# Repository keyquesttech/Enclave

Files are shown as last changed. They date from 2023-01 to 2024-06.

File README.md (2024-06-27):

<p align="center" style="margin-bottom: 0px !important;">
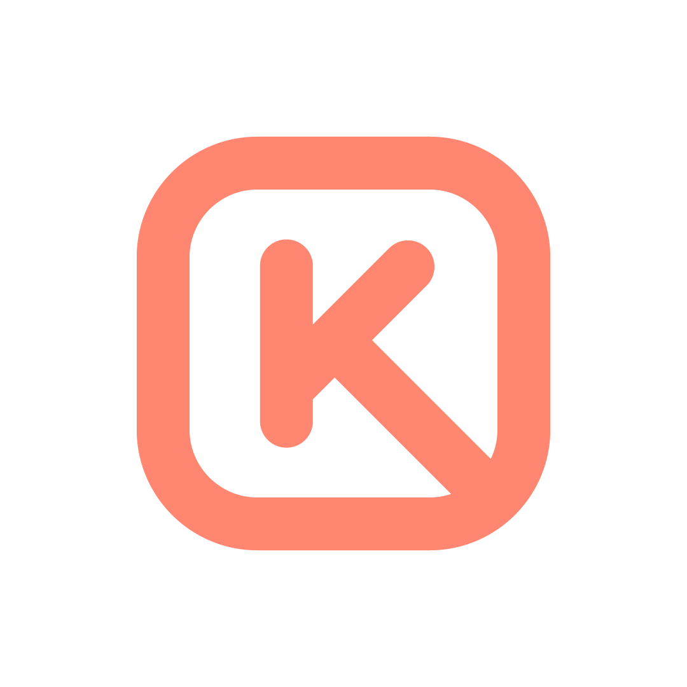
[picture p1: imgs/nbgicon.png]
Keyquest logo
  
</p>
<h1 align="center" style="margin-top: 0px;">Keyquest Keyboards</h1>
<p align="center" >Developed As Part Of My Industrial Design Thesis</p>
<p align="center" >Some Aspects Of This Project Are In Spanish</p>
<p align="center" >Developed by Matias M.</p>

<p align="center" style="margin-bottom: 0px !important;">
  <a href="https://github.com/Mathiaszmrga">
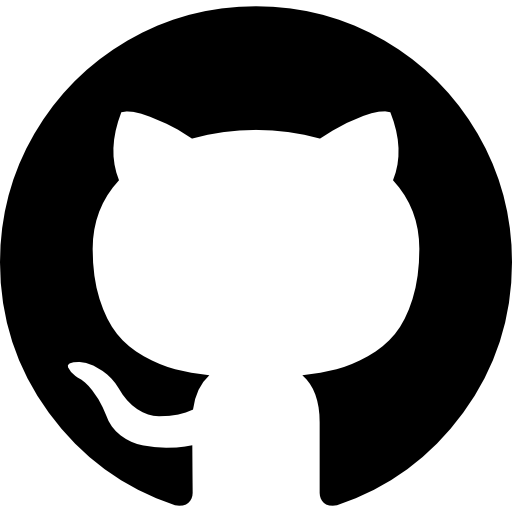
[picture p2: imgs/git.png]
    
  </a>
 <a href="https://www.behance.net/matiasms">
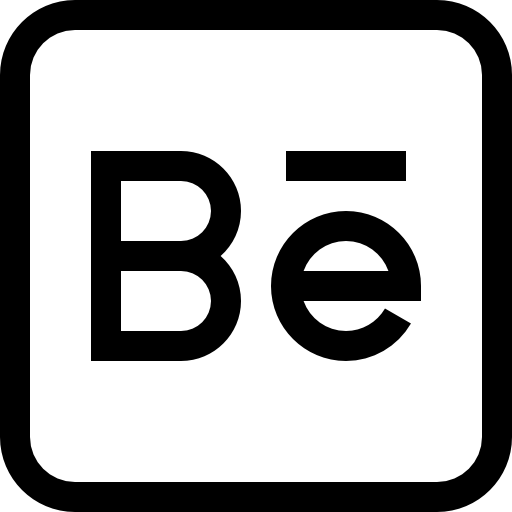
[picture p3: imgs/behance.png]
    
  </a>

<div align="center" >
  
  
  
  
  
  
</div>
  
<p align="center" style="margin-top: 100px !important;">
  <h2 align="center" style="margin-bottom: 0px;">Versions And Repo Content</h2>
</p>

<p align="center" style="margin-bottom: 0px !important;">
  <a href="https://github.com/keyquesttech/Enclave/tree/main/Enclave-1/stm">
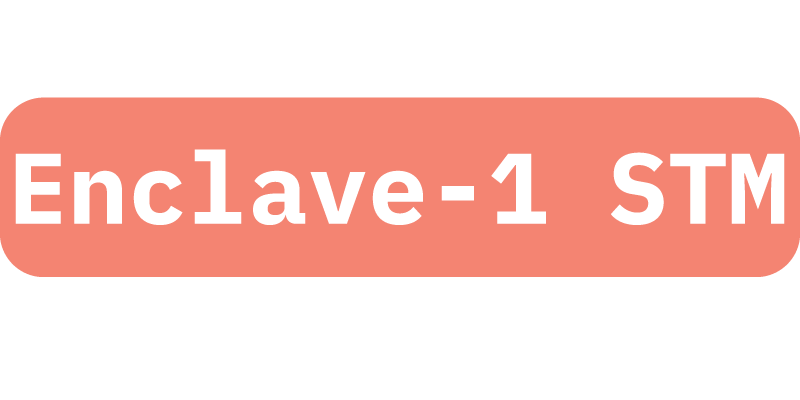
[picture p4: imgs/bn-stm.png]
    
  </a>
 <a href="https://github.com/keyquesttech/Enclave/tree/main/Enclave-1/avr">
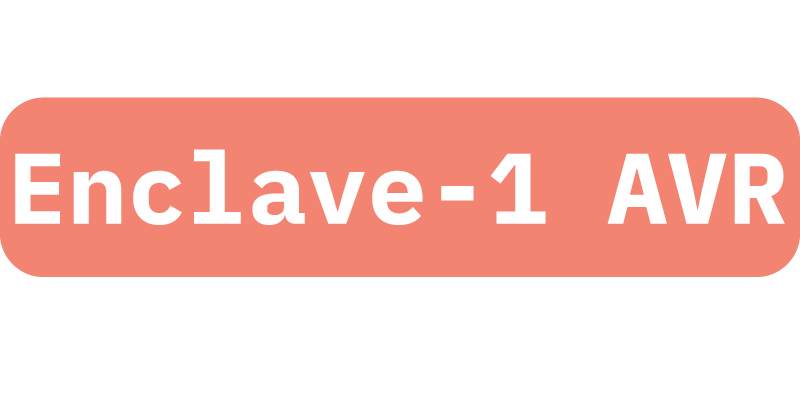
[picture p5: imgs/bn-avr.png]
    
  </a>
  
</p>

<p align="center" style="margin-top: 0px !important;">
  <h2 align="center" style="margin-bottom: 0px;">Table of Contents (Enclave-1)</h2>
</p>

<p align="center" style="margin-bottom: 0px !important;">
  adf
</p>

<p align="center" style="margin-bottom: 0px !important;">
  <h2 align="center" style="margin-top: 0px;"></h2>
</p>

- [Features](#Features)
- [Repo Content](#Repo-Content)
  - [STM](#STM)
  - [AVR](#AVR)
  - [Plate](#Plate)
- [Case](#Case)
- [Code](#Code)
  - [QMK](#QMK)
  - [VIA](#VIA)
  - [VIAL](#VIAL)
- [Suppliers](#Suppliers)
- [Contributing](#contributing)
- [Copyright and License](#copyright-and-license)

## Features:

- Lightweight.
- Cherry MX Compatible.
- Kailh Hotswap Sockets
- RGB Underglow.
- QMK, VIA And VIAL Compatible.
- Customizable.
- USB-C Interphase.
- Built In USB-HUB.

## Repo Content:

All files necessary for reproduction, manufacturing and modifications

| Branch | Content |
|--|--|
| AVR | Files for AVR (arduino) based PCB |
| STM| Files for STM based PCB |
| Plate| Files for FR-4 plate manufacturing |
| Imgs| Images on this repo and product pics |

### STM:

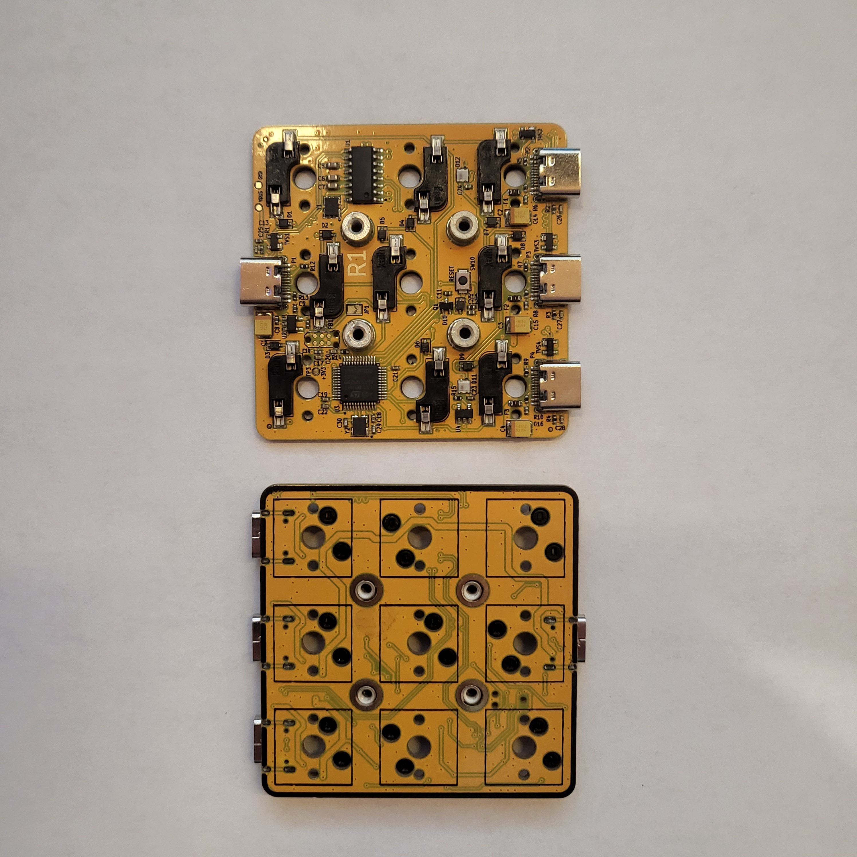
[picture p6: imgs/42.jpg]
  

| Branch | Content |
|--|--|
| 3D| PCB 3D files |
| Datasheet| Datasheet of components used |
| Docs| DXF of PCB outline |
| ZIP Full| KiCad full source file |
| Enclave_stm_sch.pdf| PDF schematic |
| Enclave_stm_BOM.pdf| PDF Bill of materials|

This version of the PCB didn't work at first and it was forgotten in favor of AVR. Use at your own risk.

### AVR:

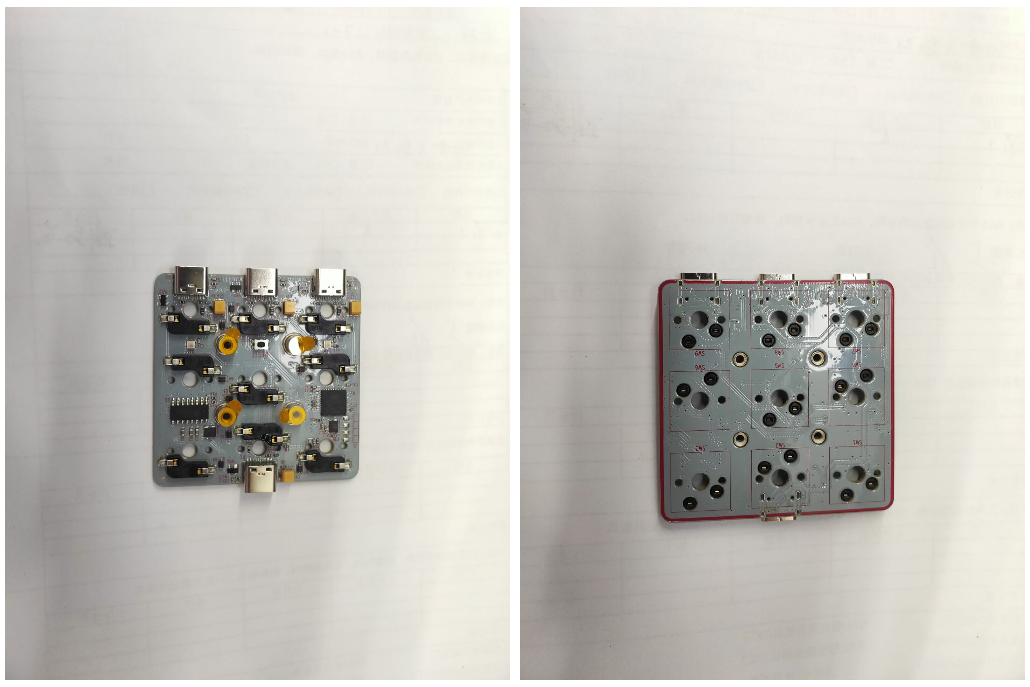
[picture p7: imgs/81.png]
  

| Branch | Content |
|--|--|
| Datasheet| Datasheet of components used |
| Docs| DXF of PCB outline |
| Production| Production files |
| ZIP Full| KiCad full source file |
| Enclave_avr_BOM.pdf| PDF Bill of materials|
| Enclave_avr_sch.pdf| PDF schematic |

### Plate:

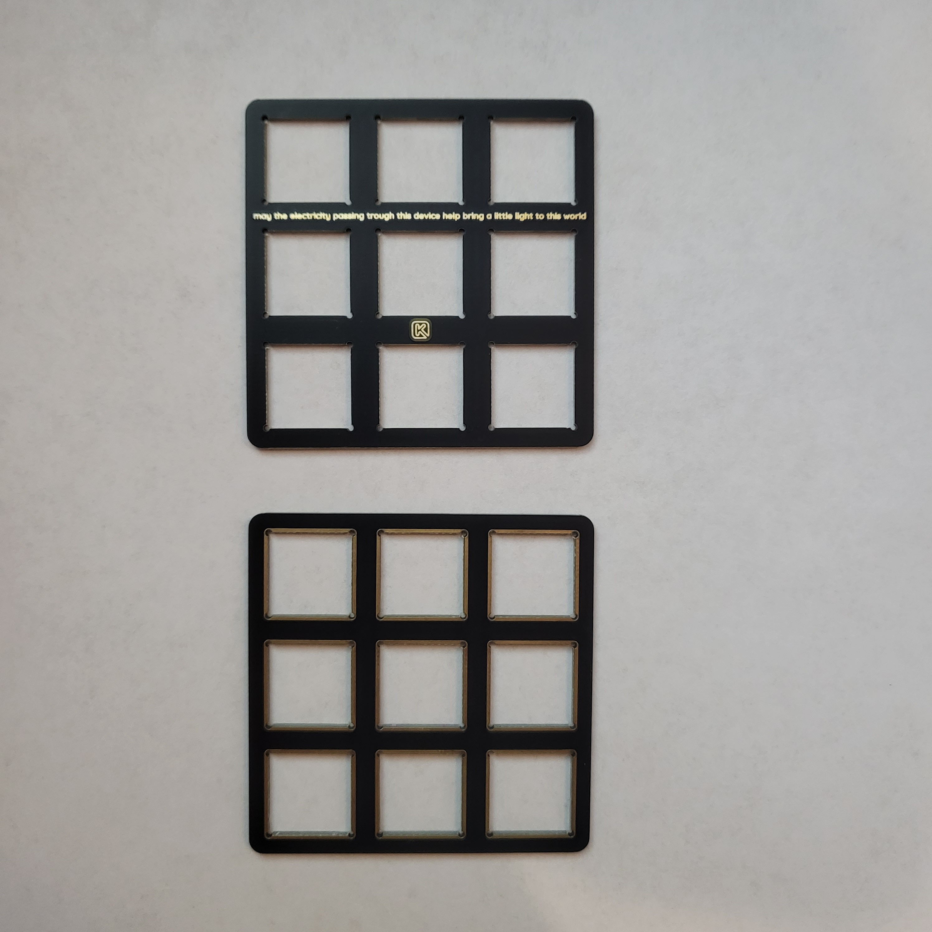
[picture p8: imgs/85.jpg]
  

| Branch | Content |
|--|--|
| DXF SRC| FR-4 Plate DXF source file |
| EasyEDA SRC| EasyEDA JSON PCB source file |
| Plate Gerber| Production files |

## Case:

  

| Branch | Content |
|--|--|
| Case_one_part.step| STEP file of for the case |
| Case_one_part_Drawing.pdf| Technical drawings of the case |

## Code:

Source code files.
- [QMK repo](https://github.com/qmk/qmk_firmware)
- [VIA repo](https://github.com/the-via/keyboards)
- [VIAL repo](https://github.com/vial-kb/vial-qmk)

### QMK:

QMK code, just add to the kyeboards directory and compile or edit as desired. it's currently merged into main so it works on official website and tools.

### VIA:

VIA can be used for local upload of JSON but it's currently merged into main so it works on official website.

### VIAL:

VIAL Source code, merged into main so it works when compiling official branch.

## Suppliers:

**Information on the service providers used for the project**

| Supplier| Contact| Thing |
|--|--|-|
| Elecrow| [Elecrow](https://www.elecrow.com/) | CNC machining
| Elecrow| [Elecrow](https://www.elecrow.com/) | PCB manufacturing
| Upwork| [Alberto M.](https://www.upwork.com/freelancers/~01b4ecb4cf82c98eb9) | PCB design
| Alibaba| echo@hzyinzheng.com | Adhesive feet

## Contributing

All contributions are welcome and encouraged.

## Copyright and License

Released under the MIT license.

<hr>

<div align="center">
  <strong><h1>Other projects from the autor (me)</h1></strong>
</div>

3D models / Prints:
 - [Mason jar ashtray](https://www.printables.com/model/918749-ashtray-mason-jar)
A mason jar attachment to make almost every jar in to an ashtray.

Printer mods:
 - [Servo nozzle brush (printables).](https://www.printables.com/model/913748-ratrig-vcore-331-servo-nozzle-brush)
A servo attached nozzle brush.
 - [Servo nozzle brush (github).](https://github.com/keyquesttech/Ratrig-Vcore-3-3.1-servo-nozzle-brush)
A servo attached nozzle brush.
 - [Endstops.](https://github.com/keyquesttech/3d_printer_endstops)
A collection of custom endstops for 3d printers or cnc machines. 
 - [Thermexp.](https://github.com/keyquesttech/Thermexp)
A PCB to add more thermistors to a klipper printer.

Chrome extensions:
 - [Youtube ads auto skip.](https://github.com/keyquesttech/chrome-extensions)
A chrome extension that emulates a click and auto skips youtube ads. Works even after adblock prevention measures.

Keyboards:
 - [Enclave.](https://github.com/keyquesttech/Enclave)
A custom mechanical switch macro pad. Works on QMK and can be used with klipper.

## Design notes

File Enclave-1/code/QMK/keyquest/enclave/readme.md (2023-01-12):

# Enclave-1

ok

Enclave 1 is a fully programmable 9-key macropad + usb hub ideal for those constantly on the move that need to adapt to any situation. Besides being a full-fledged macropad, it can also be used as the main hub for all your other devices such as keyboards, dongles, drives, etc.

* Keyboard Maintainer: [KeyQuest](https://github.com/KeyQuest)

Compile example for this keyboard (after setting up your build environment):

    make keyquest/enclave:default

Enter the bootloader in 3 ways:

* **Bootmagic reset**: Hold down the  top left key and plug in the keyboard.
* **Physical reset button**: Briefly press the button on the back of the PCB.

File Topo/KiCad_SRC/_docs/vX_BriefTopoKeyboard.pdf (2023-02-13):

### Brief diseño de teclado Topo

Funciones:
- Switches low profile “KAILH-PG1350-1U-NOLED”
- https://github.com/keebio/Keebio-Parts.pretty
- Estabilizador para teclas de 2U “KAILH PG1350 CHOC 2U STABILIZER PCB CUTOUT”
- https://github.com/keebio/Keebio-Parts.pretty
- 4x LEDs:
- Rojo para poder.
- 3 blancos conectados a pines.
- 1x USB-C.
- Standoffs SMD.

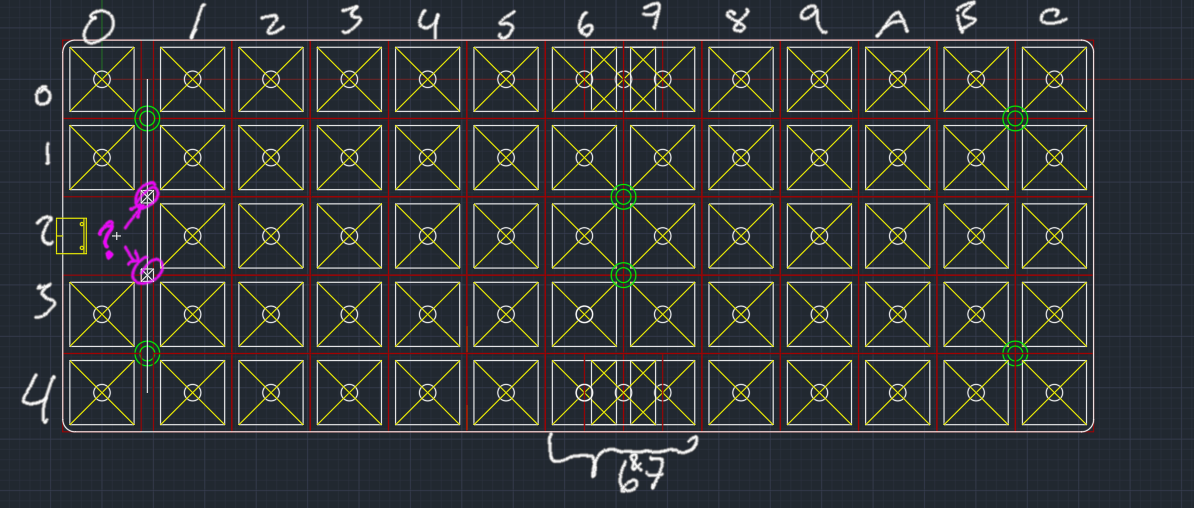
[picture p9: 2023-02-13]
Topo/KiCad_SRC/_docs/v1_layout_mod.png

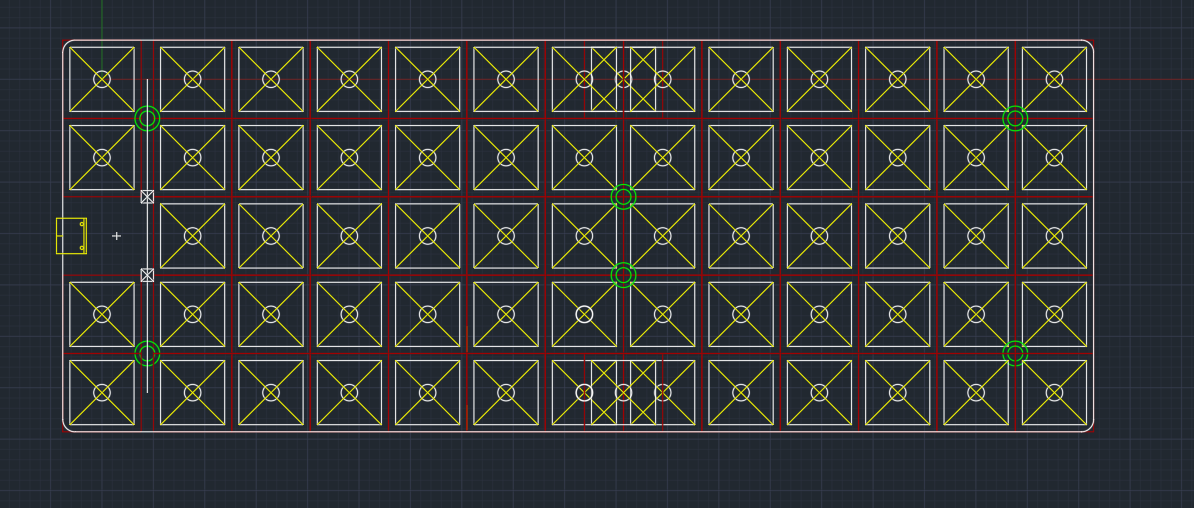
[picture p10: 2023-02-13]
Topo/KiCad_SRC/_docs/v1_layout.png

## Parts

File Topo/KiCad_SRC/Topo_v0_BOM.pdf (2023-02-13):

Topo_v0

Source: | Topo_v0.kicad_sch
Date: | Sun 12 Feb 2023 08:32:24 PM -04
Tool: | Eeschema 6.0.11-2627ca5db0~126~ubuntu22.04.1
Component Count: | 296
Item | Qty | Ref(s) | Value | Digi-Key | LCSC | Manufacturer | Mouser | Package_LCSC | Part Number
1 | 1 | C1 | 100uF/6.3V | 478-3877-1-ND | C7195 | KYOCERA AVX | 581-TAJB107M006R | CASE-B-3528 | TAJB107M006RNJ
2 | 6 | C2-7 | 1uF/16V | 1276-1067-1-ND | C29266 | Samsung Electro-Mechanics | 187-CL05A105KO5NNNC | 0402 | CL05A105KO5NNNC
3 | 72 | C8-79 | 0.1uF/16V | 1276-1001-1-ND | C1525 | Samsung Electro-Mechanics | 187-CL05B104KO5NNNC | 0402 | CL05B104KO5NNNC
4 | 1 | C80 | 1nF/50V | 1276-1032-1-ND | C14442 | Samsung Electro-Mechanics | 187-CL05B102KB5NNNC | 0402 | CL05B102KB5NNNC
5 | 2 | C81-82 | 22pF/50V | 1276-1116-1-ND | C70464 | Samsung Electro-Mechanics | 187-CL05C220JB5NNNC | 0402 | CL05C220JB5NNNC
6 | 64 | D1-64 | SD103AWS-TP | SD103AWSTPMSCT-ND | C779513 | Micro Commercial Co | 833-SD103AWS-TP | SOD-323 | SD103AWS-TP
7 | 66 | D65-130 | SK6812MINI-E | 1528-4960-ND | C5149201 | Adafruit Industries LLC | 485-4960 | SMD | 4960
8 | 1 | FB1 | BLM15PX221SN1D | 490-11021-1-ND | C160973 | Murata Electronics | 81-BLM15PX221SN1D | 0402 | BLM15PX221SN1D
9 | 6 | H1-6 | MountingHole_Pad | 732-7089-1-ND | - - - | Würth Elektronik | 710-9774040151R | - - - | 9774040151R
10 | 1 | J1 | AVR-ISP | 609-4381-ND | - - - | Amphenol ICC (FCI) | 649-10112684G0304ULF | - - - | 10112684-G03-04ULF
11 | 1 | P1 | Port1 | - - - | C165948 | Korean Hroparts Elec | - - - | SMD | TYPE-C-31-M-12
12 | 1 | R1 | 1M0 | 311-1.00MLRCT-ND | C138033 | YAGEO | 603-RC0402FR-071ML | 0402 | RC0402FR-071ML
13 | 2 | R2-3 | 10K0 | 311-10.0KLRCT-ND | C60490 | YAGEO | 603-RC0402FR-0710KL | 0402 | RC0402FR-0710KL
14 | 2 | R4, R5 | 5K1 | 311-5.10KLRCT-ND | C105872 | YAGEO | 603-RC0402FR-075K1L | 0402 | RC0402FR-075K1L
15 | 1 | R6 | 499R | 311-499LRCT-ND | C137970 | YAGEO | 603-RC0402FR-07499RL | 0402 | RC0402FR-07499RL
16 | 2 | R7-8 | 22R0 | 311-22.0LRCT-ND | C114765 | YAGEO | 603-RC0402FR-0722RL | 0402 | RC0402FR-0722RL
17 | 1 | SW1 | RESET | CKN10587CT-ND | C221904 | C&K | 611-PTS830GM140GSMTR | SMD | PTS830GM140 SMTR LFS
18 | 1 | SW2 | SW_DIP_x01 | 2223-DS04-254-1-01BK-SMT-ND | C600988 | CUI Devices | 490-DS04254101BK-SMT | SMD,3.5x6.2mm | DS04-254-1-01BK-SMT
19 | 62 | SW3-64 | Choc V1 | - - - | - - - | Cherry AG | - - - | - - - | Cherry MX
21 | 1 | TVS1 | PRTR5V0U2X | 1727-3884-1-ND | C12333 | Nexperia USA Inc. | 771-PRTR5V0U2X-T/R | SOT-143 | PRTR5V0U2X,215
22 | 1 | U1 | ATmega32U4-M | ATMEGA32U4-MURCT-ND | C45874 | Microchip Technology | 556-ATMEGA32U4-MUR | VQFN-44-EP(7x7) | ATMEGA32U4-MUR
23 | 1 | Y1 | 16MHz | 535-10267-1-ND | C1985423 | Abracon LLC | 815-ABM8G-16-18D2Y | SMD-4P | ABM8G-16.000MHZ-18-D2Y-T

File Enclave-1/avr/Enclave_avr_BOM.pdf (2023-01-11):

# ENCLAVE_v0

Source: ENCLAVE_v0.kicad_sch

Date: Thu 16 Jun 2022 02:48:39 PM -04

Tool: Eeschema 6.0.5-a6ca702e91~116~ubuntu22.04.1

Component Count: 97

Item | Qty | Reference(s) | Value | Manufacturer | Part Number | Digi-Key | LCSC | Mouser
1 | 4 | C1-4 | 100uF/6.3V | KYOCERA AVX | TAJB107M006RNJ | 478-3877-1-ND | C7195 | 581-TAJB107M006R
2 | 3 | C5-7 | 10uF/10V | Samsung Electro-Mechanics | CL10A106MP8NNNC | 1276-1871-1-ND | C85713 | 187-CL10A106MP8NNNC
3 | 9 | C8-16 | 1uF/16V | Samsung Electro-Mechanics | CL05A105KO5NNNC | 1276-1067-1-ND | C29266 | 187-CL05A105KO5NNNC
4 | 8 | C17-24 | 0.1uF/16V | Samsung Electro-Mechanics | CL05B104KO5NNNC | 1276-1001-1-ND | C1525 | 187-CL05B104KO5NNNC
5 | 4 | C25-28 | 1nF/50V | Samsung Electro-Mechanics | CL05B102KB5NNNC | 1276-1032-1-ND | C14442 | 187-CL05B102KB5NNNC
6 | 2 | C29-30 | 22pF/50V | Samsung Electro-Mechanics | CL05C220JB5NNNC | 1276-1116-1-ND | C70464 | 187-CL05C220JB5NNNC
7 | 9 | D1-9 | SD103AWS-TP | Micro Commercial Co | SD103AWS-TP | SD103AWSTPMSCT-ND | C779513 | 833-SD103AWS-TP
8 | 2 | D10-11 | WS2812B-2020 | Worldsemi | WS2812B-Mini | 1528-4684-ND | C2976072 | 485-4684
9 | 3 | F1-3 | 350mA | YAGEO | SMD0603B035TF | 13-SMD0603B035TFCT-ND | C269154 | 603-SMD0603B035TF
10 | 1 | FB1 | BLM15PX221SN1D | Murata Electronics | BLM15PX221SN1D | 490-11021-1-ND | C160973 | 81-BLM15PX221SN1D
11 | 4 | H1-4 | MountingHole_Pad | Würth Elektronik | 9774040151R | 732-7089-1-ND | - - - | 710-9774040151R
12 | 1 | J1 | AVR-ISP | Amphenol ICC (FCI) | 10112684-G03-04ULF | 609-4381-ND | - - - | 649-10112684G0304ULF
13 | 4 | P1-4 | Port1-4 | Korean Hroparts Elec | TYPE-C-31-M-12 | - - - | C165948 | - - -
17 | 4 | R1-4 | 1M0 | YAGEO | RC0402FR-071ML | 311-1.00MLRCT-ND | C138033 | 603-RC0402FR-071ML
18 | 6 | R5-10 | 56K0 | YAGEO | RC0402FR-0756KL | 311-56.0KLRCT-ND | C114756 | 603-RC0402FR-0756KL
19 | 1 | R11 | 10K0 | YAGEO | RC0402FR-0710KL | 311-10.0KLRCT-ND | C60490 | 603-RC0402FR-0710KL
20 | 2 | R12-13 | 5K1 | YAGEO | RC0402FR-075K1L | 311-5.10KLRCT-ND | C105872 | 603-RC0402FR-075K1L
21 | 1 | R14 | 499R | YAGEO | RC0402FR-07499RL | 311-499LRCT-ND | C137970 | 603-RC0402FR-07499RL
22 | 2 | R15-16 | 22R0 | YAGEO | RC0402FR-0722RL | 311-22.0LRCT-ND | C114765 | 603-RC0402FR-0722RL
23 | 9 | SW1-9 | Cherry MX | Cherry AG | Cherry MX | - - - | - - - | - - -
24 | 1 | SW10 | RESET | C&K | KMR241GLFS | 401-1431-1-ND | C221682 | 611-KMR241GLFS
25 | 9 | SWS1-9 | Hot Swapping PCB Socket | Kaihua Electronics | CPG151101S11 | - - - | C2803348 | - - -
26 | 4 | TVS1-4 | PRTR5V0U2X | Nexperia USA Inc. | PRTR5V0U2X,215 | 1727-3884-1-ND | C12333 | 771-PRTR5V0U2X-T/R
27 | 1 | U1 | SL2.1A | CoreChips | SL2.1A | - - - | C192893 | - - -
28 | 1 | U2 | ATmega32U4-M | Microchip Technology | ATMEGA32U4-MUR | ATMEGA32U4-MURCT-ND | C45874 | 556-ATMEGA32U4-MUR
29 | 1 | Y1 | 12MHz | Abracon LLC | ABM8G-12.000MHZ-4Y-T3 | 535-10901-1-ND | C50430 | 815-ABM8G-12-4YT3
30 | 1 | Y2 | 16MHz | Abracon LLC | ABM8G-16.000MHZ-18-D2Y-T | 535-10267-1-ND | C1985423 | 815-ABM8G-16-18D2Y

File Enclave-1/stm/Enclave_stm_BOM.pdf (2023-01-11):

ONO_v0

Source: ONO_v0.kicad_sch

Date: Wed 25 May 2022 01:04:23 PM -04

Tool: Eeschema 6.0.5-a6ca702e91~116~ubuntu22.04.1

Component Count: 99

Item | Qty | Reference(s) | Value | Manufacturer | Part Number | Digi-Key | LCSC | Mouser
1 | 4 C1-4 | | 100uF/6.3V | KYOCERA AVX | TAJB107M006RNJ | 478-3877-1-ND | C7195 | 581-TAJB107M006R
2 | 3 C5-7 | | 10uF/10V | Samsung Electro-Mechanics | CL10A106MP8NNNC | 1276-1871-1-ND | C85713 | 187-CL10A106MP8NNNC
3 | 9 C8-16 | | 1uF/16V | Samsung Electro-Mechanics | CL05A105KO5NNNC | 1276-1067-1-ND | C29266 | 187-CL05A105KO5NNNC
4 | 8 C17-24 | | 0.1uF/16V | Samsung Electro-Mechanics | CL05B104KO5NNNC | 1276-1001-1-ND | C1525 | 187-CL05B104KO5NNNC
5 | 4 C25-28 | | 1nF/50V | Samsung Electro-Mechanics | CL05B102KB5NNNC | 1276-1032-1-ND | C14442 | 187-CL05B102KB5NNNC
6 | 2 C29-30 | | 10pF/50V | Samsung Electro-Mechanics | CL05C100JB5NNNC | 1276-1139-1-ND | C32949 | 187-CL05C100JB5NNNC
7 | 10 D1-10 | | SD103AWS-TP | Micro Commercial Co | SD103AWS-TP | SD103AWSTPMSCT-ND | C779513 | 833-SD103AWS-TP
8 | 2 D11-12 | | WS2812B-2020 | Worldsemi | WS2812B-Mini | 1528-4684-ND | C2976072 | 485-4684
9 | 3 F1-3 | | 350mA | YAGEO | SMD0603B035TF | 13-SMD0603B035TFCT-ND | C269154 | 603-SMD0603B035TF
10 | 1 FB1 | | BLM15PX221SN1D | Murata Electronics | BLM15PX221SN1D | 490-11021-1-ND | C160973 | 81-BLM15PX221SN1D
11 | 4 H1-4 | | MountingHole_Pad | Würth Elektronik | 9774040151R | 732-7089-1-ND | - - - | 710-9774040151R
12 | 4 P1-4 | | Port1-4 | Korean Hroparts Elec | TYPE-C-31-M-12 | - - - | C165948 | - - -
13 | 1 Q1 | | PDTC143ZU,115 | Nexperia USA Inc. | PDTC143ZU,115 | 1727-1714-1-ND | C282553 | 771-PDTC143ZU115
14 | 4 R1-4 | | 1M0 | YAGEO | RC0402FR-071ML | 311-1.00MLRCT-ND | C138033 | 603-RC0402FR-071ML
15 | 6 R5-10 | | 56K0 | YAGEO | RC0402FR-0756KL | 311-56.0KLRCT-ND | C114756 | 603-RC0402FR-0756KL
16 | 1 R11 | | 10K0 | YAGEO | RC0402FR-0710KL | 311-10.0KLRCT-ND | C60490 | 603-RC0402FR-0710KL
17 | 2 R12-13 | | 5K1 | YAGEO | RC0402FR-075K1L | 311-5.10KLRCT-ND | C105872 | 603-RC0402FR-075K1L
18 | 1 R14 | | 1K5 | YAGEO | RC0402FR-071K5L | 311-1.50KLRCT-ND | C114759 | 603-RC0402FR-071K5L
19 | 1 R15 | | 499R | YAGEO | RC0402FR-07499RL | 311-499LRCT-ND | C137970 | 603-RC0402FR-07499RL
20 | 9 SW1-9 | | Cherry MX | Cherry AG | Cherry MX | - - - | - - - | - - -
21 | 1 SW10 | | RESET | Omron Electronics Inc-EMC Div | B3U-1000P | SW1020CT-ND | C231329 | 653-B3U-1000P
22 | 9 SWS1-9 | | Hot Swapping PCB Socket | Kaihua Electronics | CPG151101S11 | - - - | C2803348 | - - -
23 | 4 TVS1-4 | | PRTR5V0U2X | Nexperia USA Inc. | PRTR5V0U2X,215 | 1727-3884-1-ND | C12333 | 771-PRTR5V0U2X-T/R
24 | 1 U1 | | SL2.1A | CoreChips | SL2.1A | - - - | C192893 | - - -
25 | 1 U2 | | TLV73333PDBV | Texas Instruments | TLV73333PDBVR | 296-40673-1-ND | C134139 | 595-TLV73333PDBVR
26 | 1 U3 | | STM32F303CBTx | STMicroelectronics | STM32F303CBT6 | 497-17421-ND | C108516 | 511-STM32F303CBT6
27 | 1 U4 | | 74LVC1G34 | Texas Instruments | SN74LVC1G34DBVR | 296-17893-1-ND | C840096 | 595-SN74LVC1G34DBVR
28 | 2 Y1-2 | | 12MHz | Abracon LLC | ABM8G-12.000MHZ-4Y-T3 | 535-10901-1-ND | C50430 | 815-ABM8G-12-4YT3

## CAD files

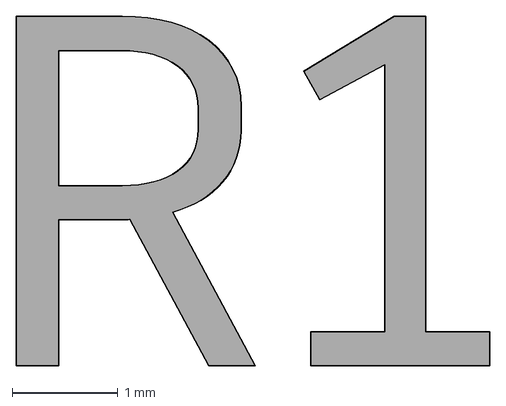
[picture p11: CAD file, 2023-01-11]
Enclave-1/avr/Docs/Rev_logo.dxf
4.48 x 3.31 mm

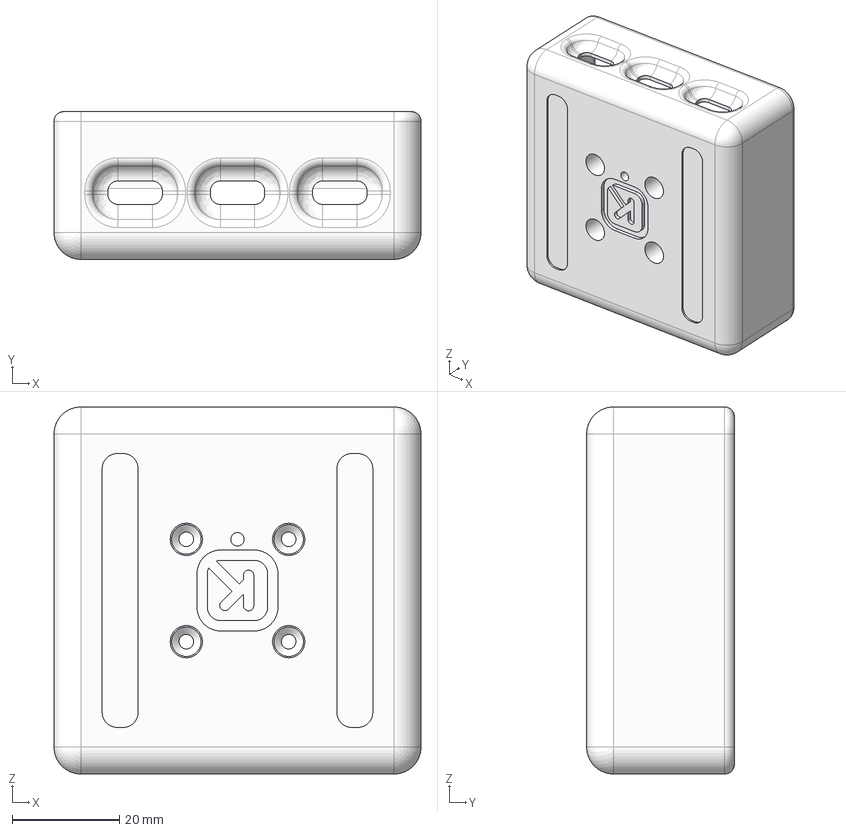
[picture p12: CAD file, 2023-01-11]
Enclave-1/case/Case_one_part.step
68.3 x 27.5 x 68.3 mm

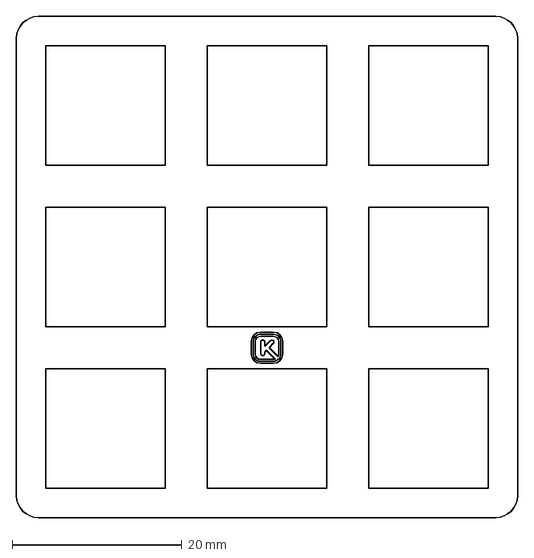
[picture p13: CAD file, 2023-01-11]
Enclave-1/plate/DXF_src/FR-4_plate_V1.dxf
59.1 x 59.1 mm

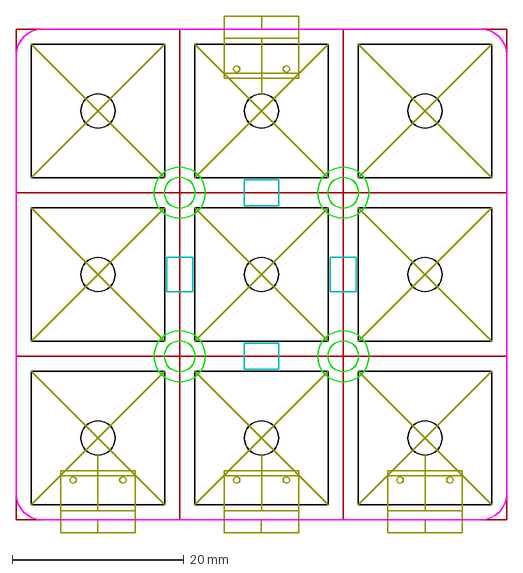
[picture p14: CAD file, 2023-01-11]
Enclave-1/stm/Docs/Outline.dxf
57.2 x 60.2 mm

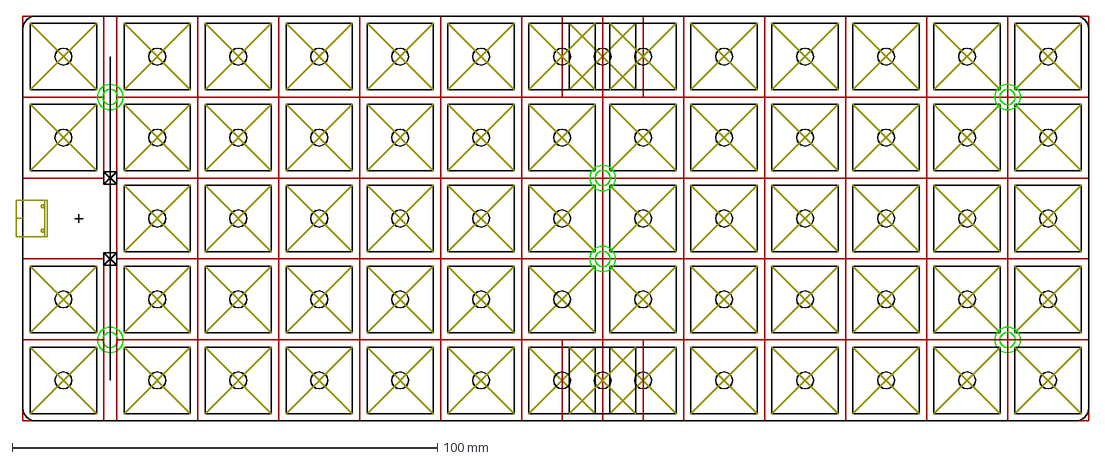
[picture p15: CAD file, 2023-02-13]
Topo/KiCad_SRC/_docs/v1_Outline.dxf
252.2 x 95.3 mm

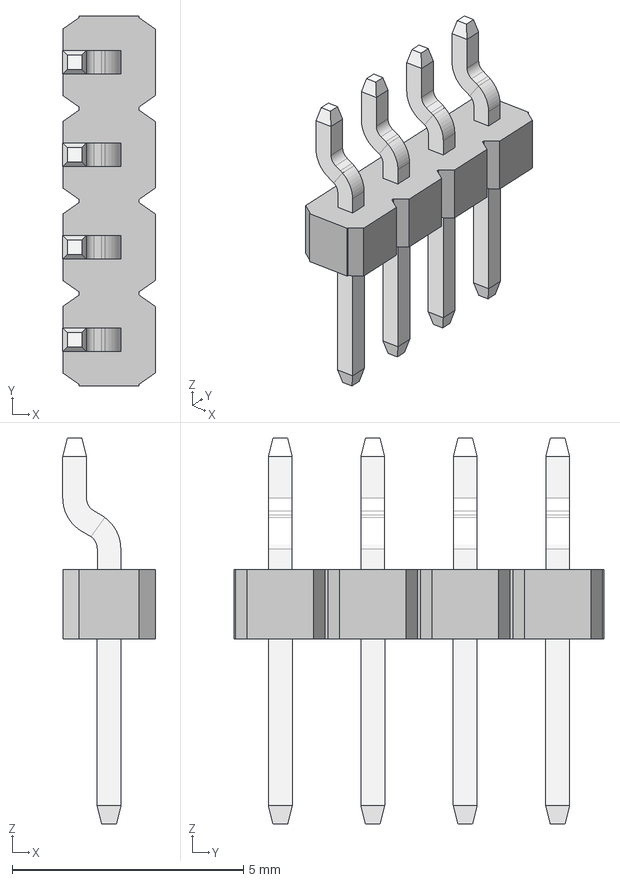
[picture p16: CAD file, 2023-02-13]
Topo/KiCad_SRC/_local/PinHeader_1x04_Amphenol_10112684-G03-04ULF.step
2.00 x 8.00 x 8.35 mm

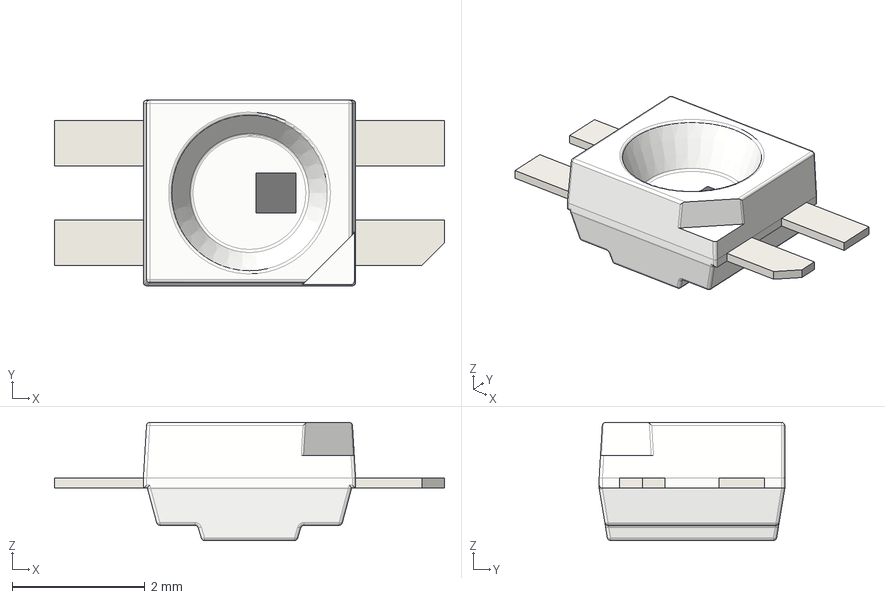
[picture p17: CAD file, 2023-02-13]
Topo/KiCad_SRC/_local/LED_OPSCO-Optoelectronics_SK6812MINI-E.step
5.88 x 2.80 x 1.78 mm

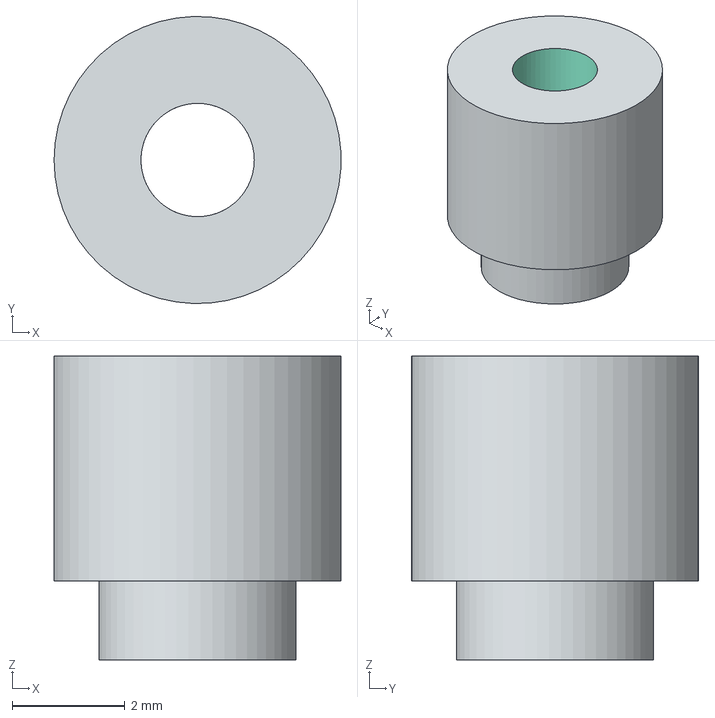
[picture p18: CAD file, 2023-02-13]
Topo/KiCad_SRC/_local/Standoff_M2d5_Wurth_9774040151R.step
5.10 x 5.10 x 5.40 mm

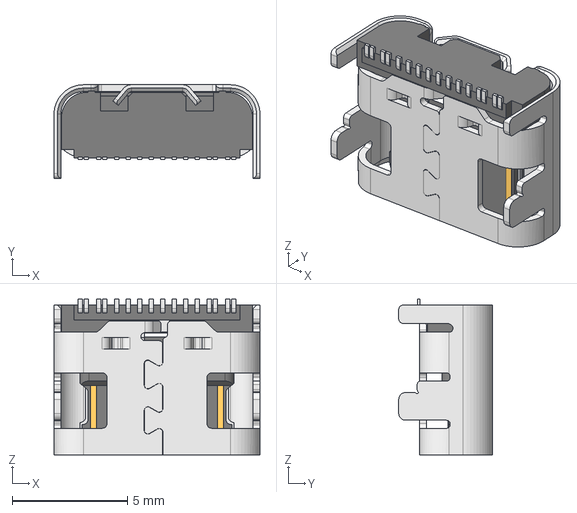
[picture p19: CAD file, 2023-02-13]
Topo/KiCad_SRC/_local/USB_C_Receptacle_Molex_2171790001.step
8.94 x 4.06 x 6.75 mm

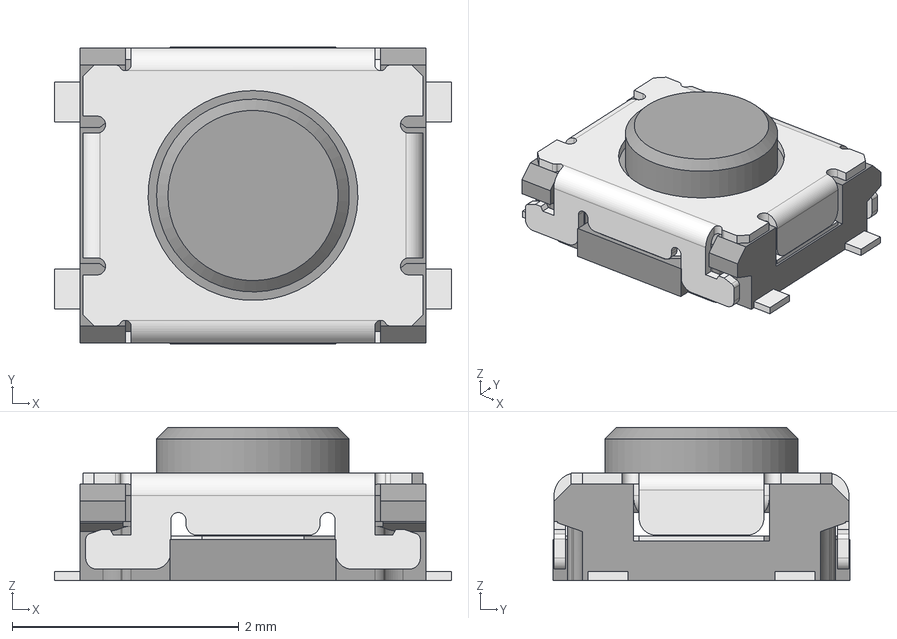
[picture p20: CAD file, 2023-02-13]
Topo/KiCad_SRC/_local/SW_SPST_CandK_PTS830.step
3.50 x 2.62 x 1.35 mm
PTS830
CubeFixColor

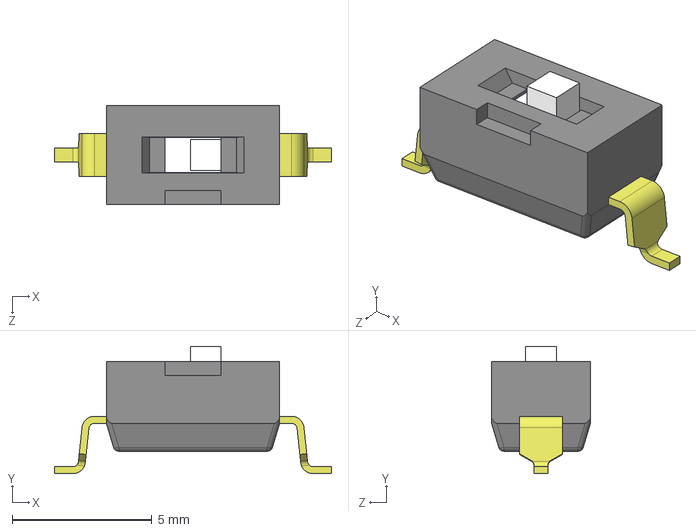
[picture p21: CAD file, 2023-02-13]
Topo/KiCad_SRC/_local/SW_DIP_SPSTx01_Slide_CUI_DS04-254-1-01BK-SMT_W6.20mm_P2.54mm.step
9.90 x 4.55 x 3.54 mm

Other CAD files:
Topo/KiCad_SRC/_docs/#v1_Outline.dwg
Topo/KiCad_SRC/_docs/v1_Outline.dwg

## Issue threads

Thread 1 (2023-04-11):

About screw

F1hone, 2023-04-11:
Your work is impressive
I love it so much and am about to make one myself
But I have a small question, what type of screws should I use
Looking forward to your reply

keyquesttech, 2024-06-27:
Hello. sorry for the late reply. Depends on the standoffs you use but if you go with the "stock" components M2.5x 6 or 12mm would work fine.

Closed 2024-06-27.

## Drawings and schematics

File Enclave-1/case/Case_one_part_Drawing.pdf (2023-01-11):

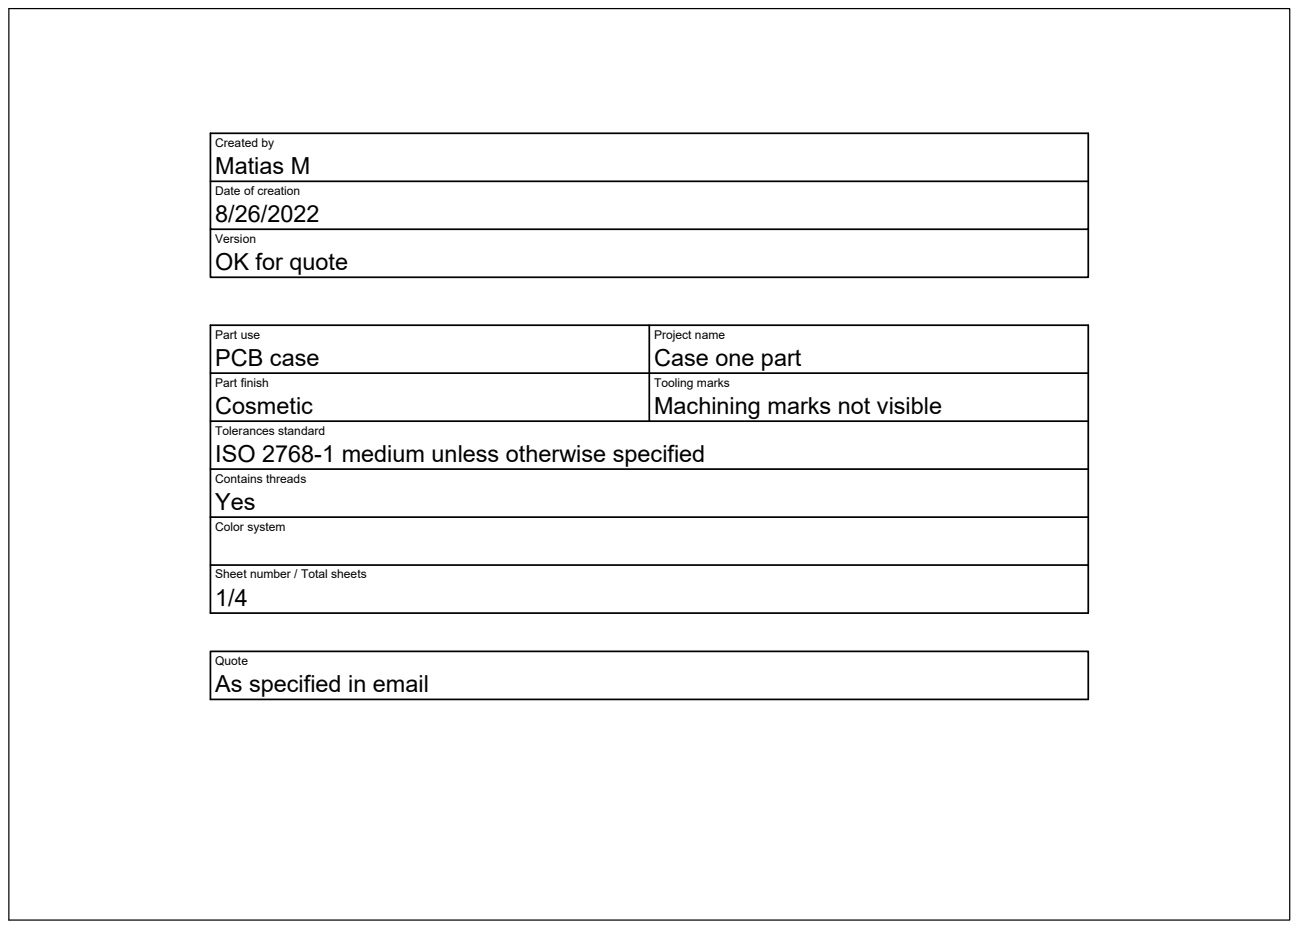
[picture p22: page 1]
Contains threads; Color system; Created by Matias M

Date of creation

Version
OK for quote

Part use PCB case | Project name Case one part

Part finish Cosmetic | Tooling marks Machining marks not visible

Tolerances standard
ISO 2768-1 medium unless otherwise specified

Sheet number / Total sheets

Quote
As specified in email

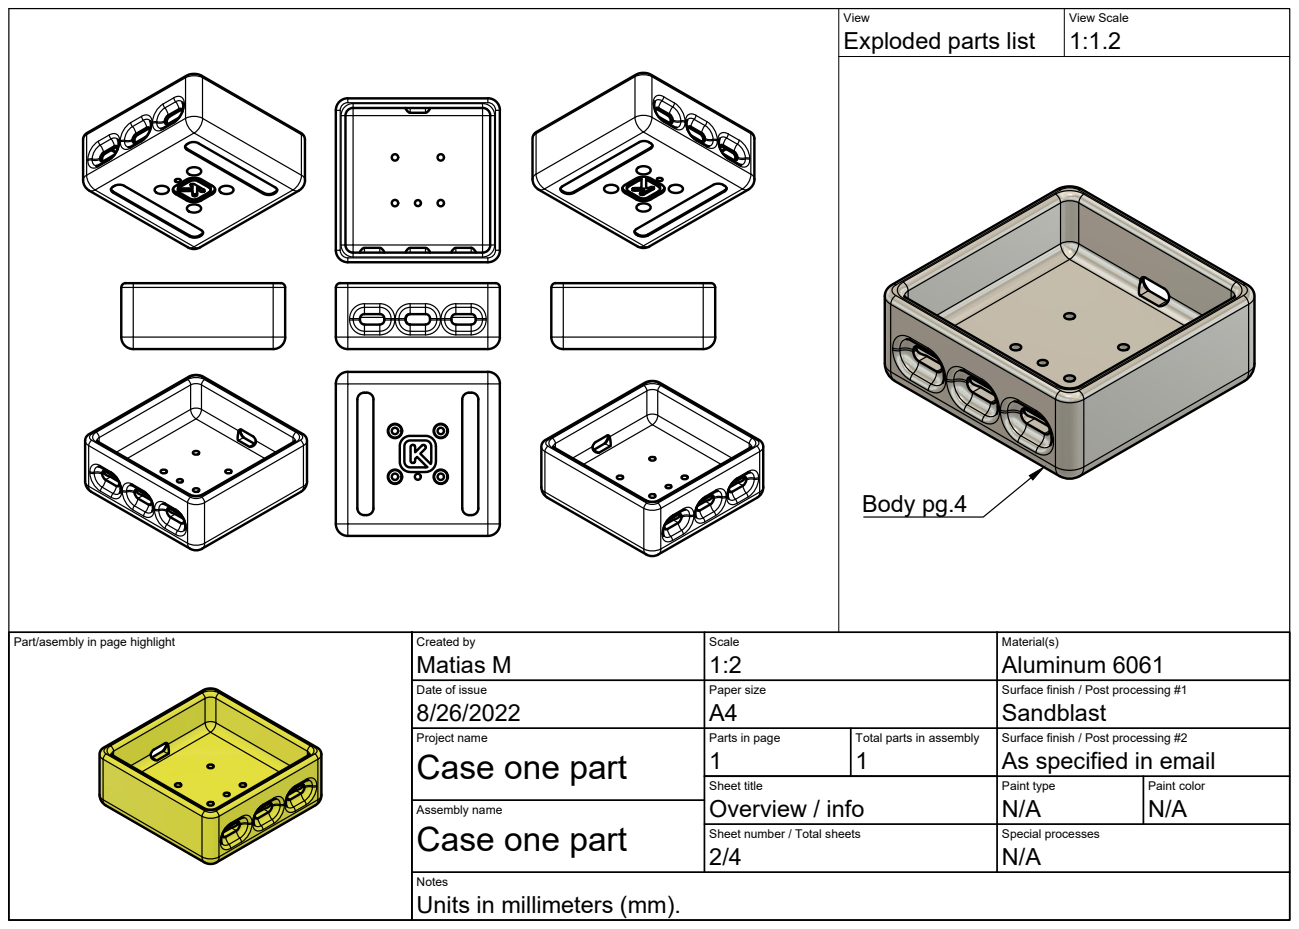
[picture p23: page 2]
View; View Scale; Exploded parts list; Body pg.4

Part/asembly in page highlight | Created by Matias M | Scale 1:2 | Material(s) Aluminum 6061

Date of issue 8/26/2022 | Paper size A4 | Surface finish / Post processing #1 Sandblast

Project name Case one part | Parts in page 1 | Total parts in assembly 1 | Surface finish / Post processing #2 As specified in email

Sheet title Overview / info | Paint type N/A | Paint color N/A

Assembly name
Case one part

Sheet number / Total sheets 2/4 | Special processes N/A

Notes
Units in millimeters (mm).

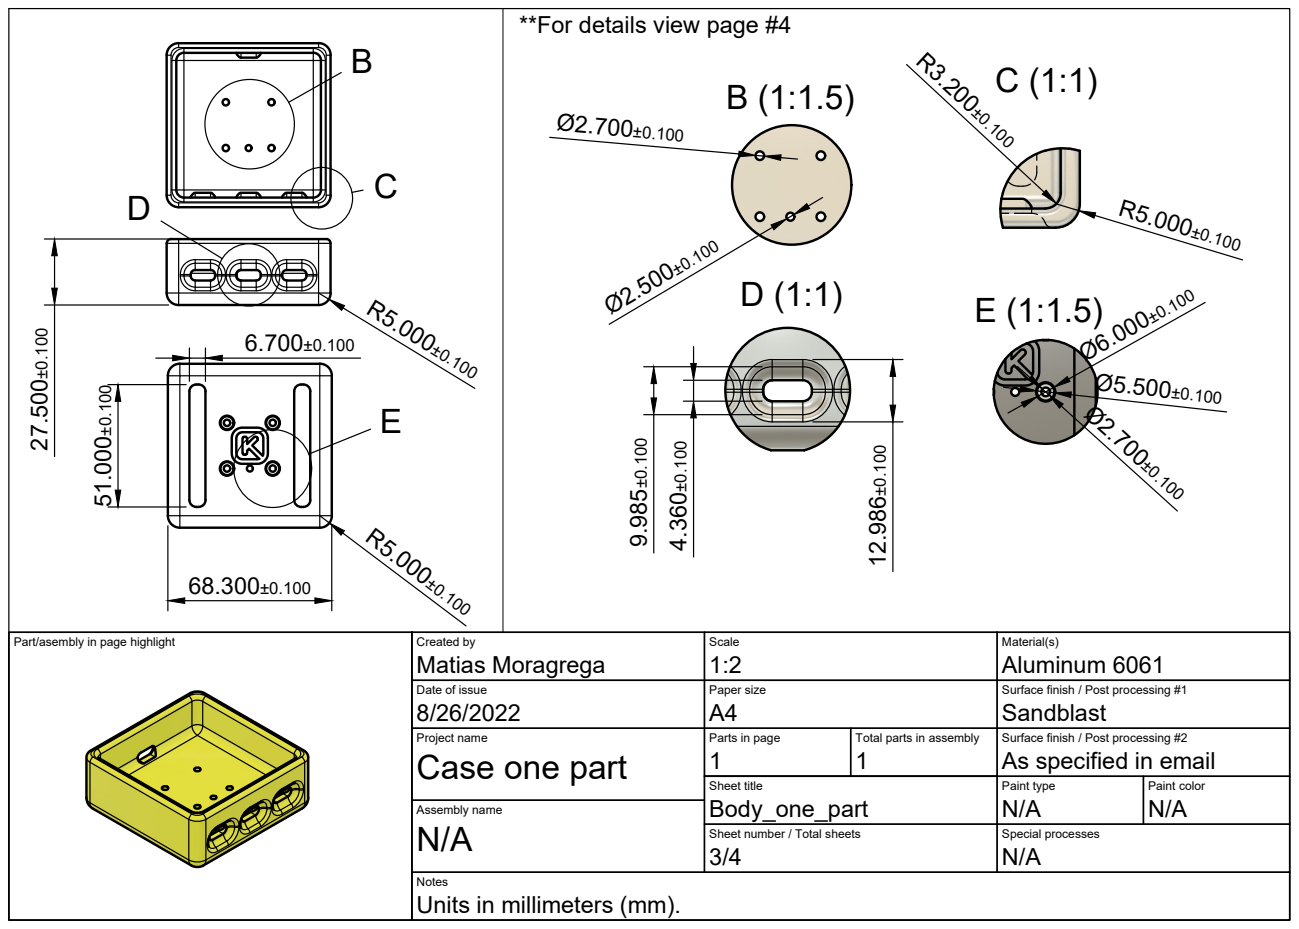
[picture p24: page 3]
Assembly name

**For details view page #4

Part/asembly in page highlight | Created by Matias Moragrega | Scale 1:2 | Material(s) Aluminum 6061

Date of issue 8/26/2022 | Paper size A4 | Surface finish / Post processing #1 Sandblast

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

Sheet title Body_one_part | Paint type N/A | Paint color

Sheet number / Total sheets 3/4 | Special processes N/A

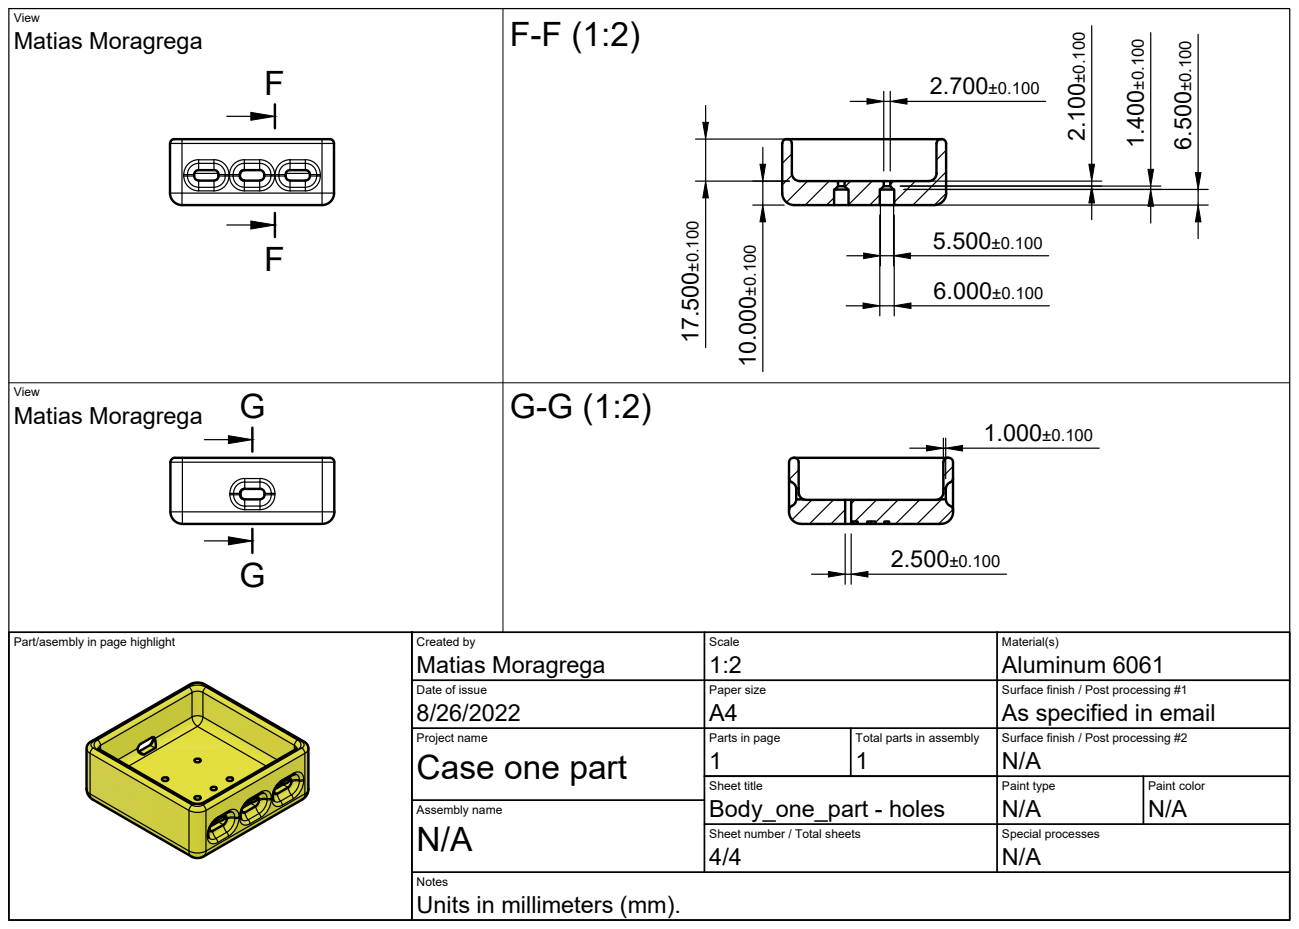
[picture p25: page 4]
Assembly name; Matias Moragrega

Part/asembly in page highlight | Created by Matias Moragrega | Scale 1:2 | Material(s) Aluminum 6061

Date of issue 8/26/2022 | Paper size A4 | Surface finish / Post processing #1 As specified in email

Project name Case one part | Parts in page 1 | Total parts in assembly 1 | Surface finish / Post processing #2 N/A

Sheet title Body_one_part - holes | Paint type N/A | Paint color N/A

Sheet number / Total sheets 4/4 | Special processes N/A

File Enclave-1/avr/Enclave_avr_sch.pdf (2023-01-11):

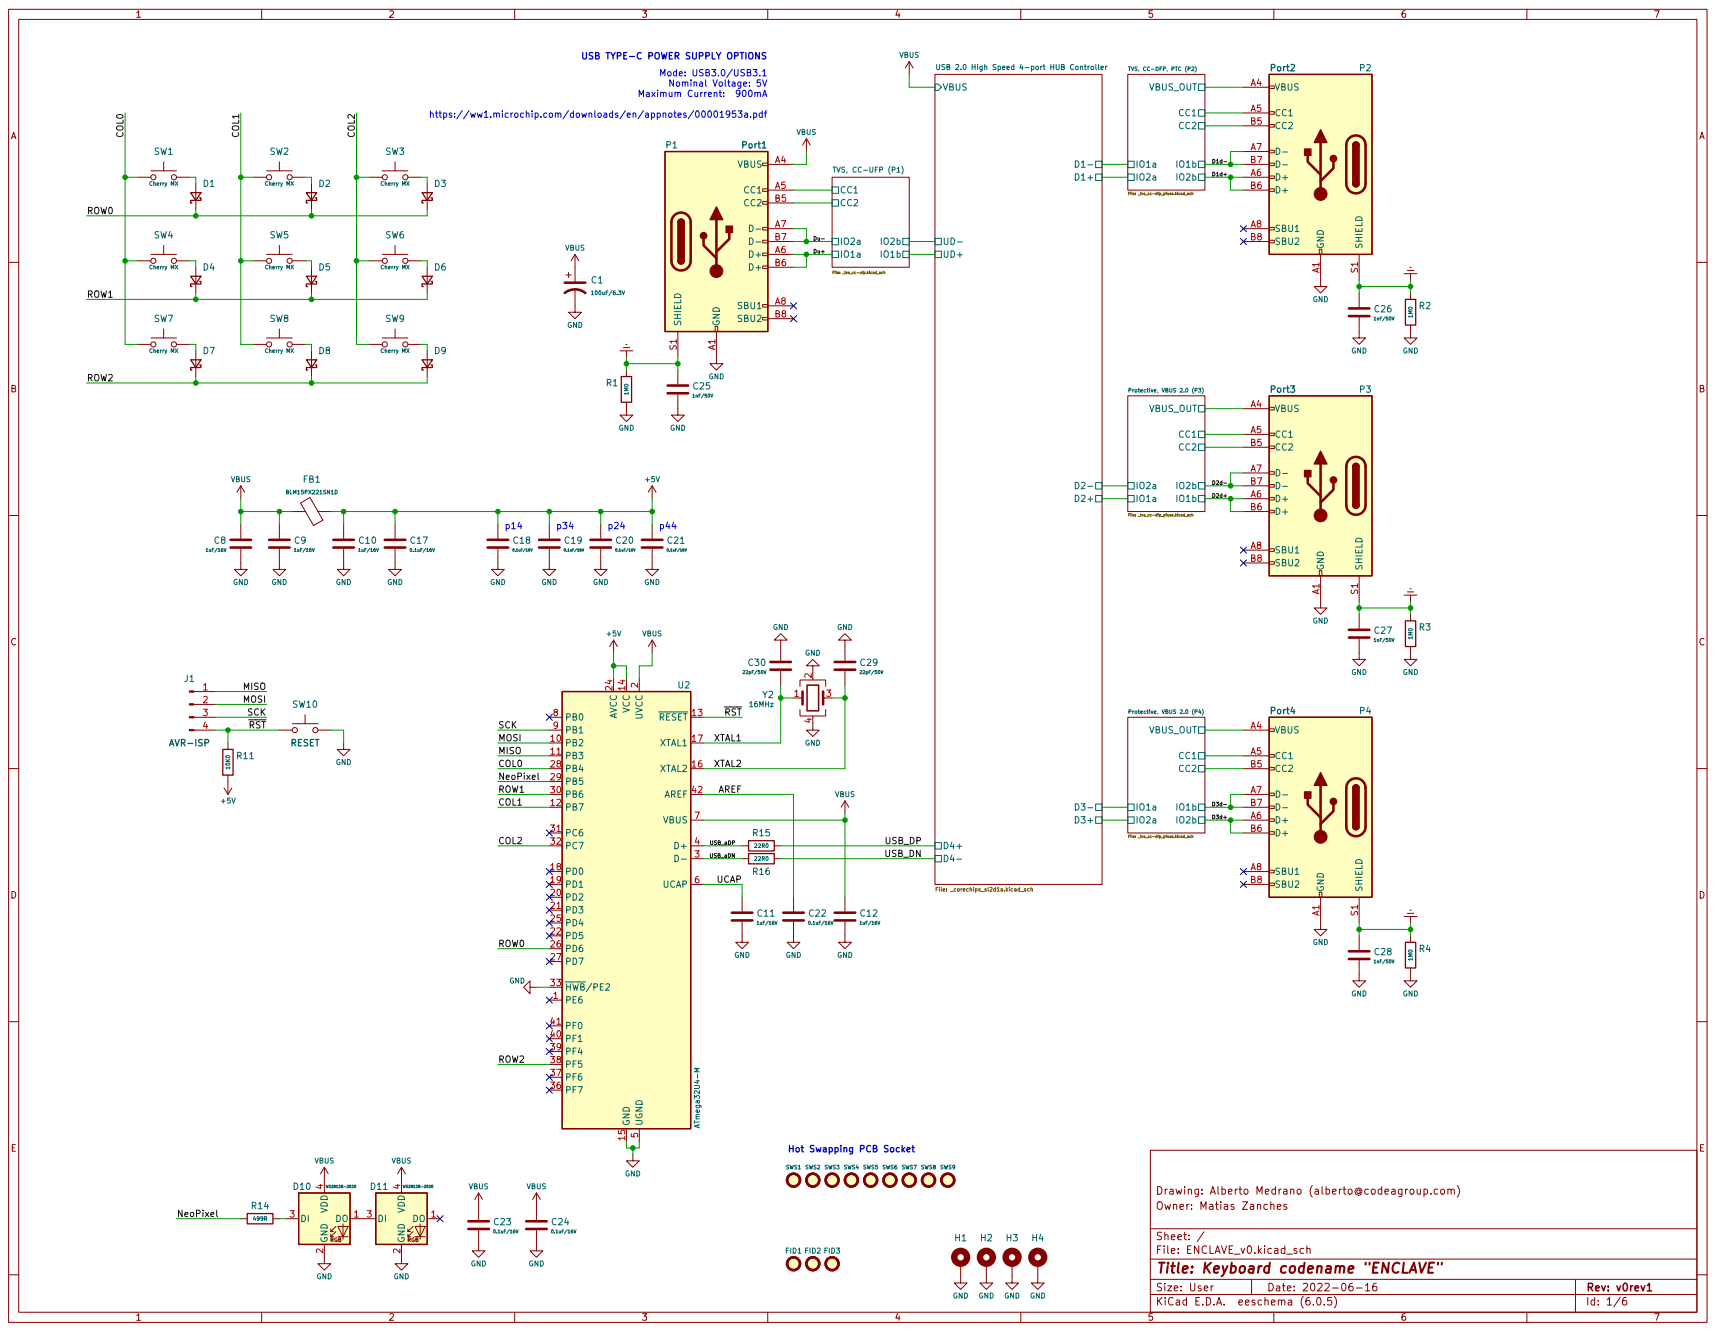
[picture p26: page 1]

USB 2.0 High Speed 4-port HUB Controller
Cherry MX SW4

USB TYPE-C POWER SUPPLY OPTIONS Mode: USB3.0/USB3.1 Nominal Voltage: 5V Maximum Current: 900mA

https://ww1.microchip.com/downloads/en/appnotes/00001953a.pdf

USB_aDN | 22R0

File: ENCLAVE_v0.kicad_sch Sheet: / Owner: Matias Zanches Drawing: Alberto Medrano (alberto@codeagroup.com)

Id: 1/6 Title: Keyboard codename "ENCLAVE"

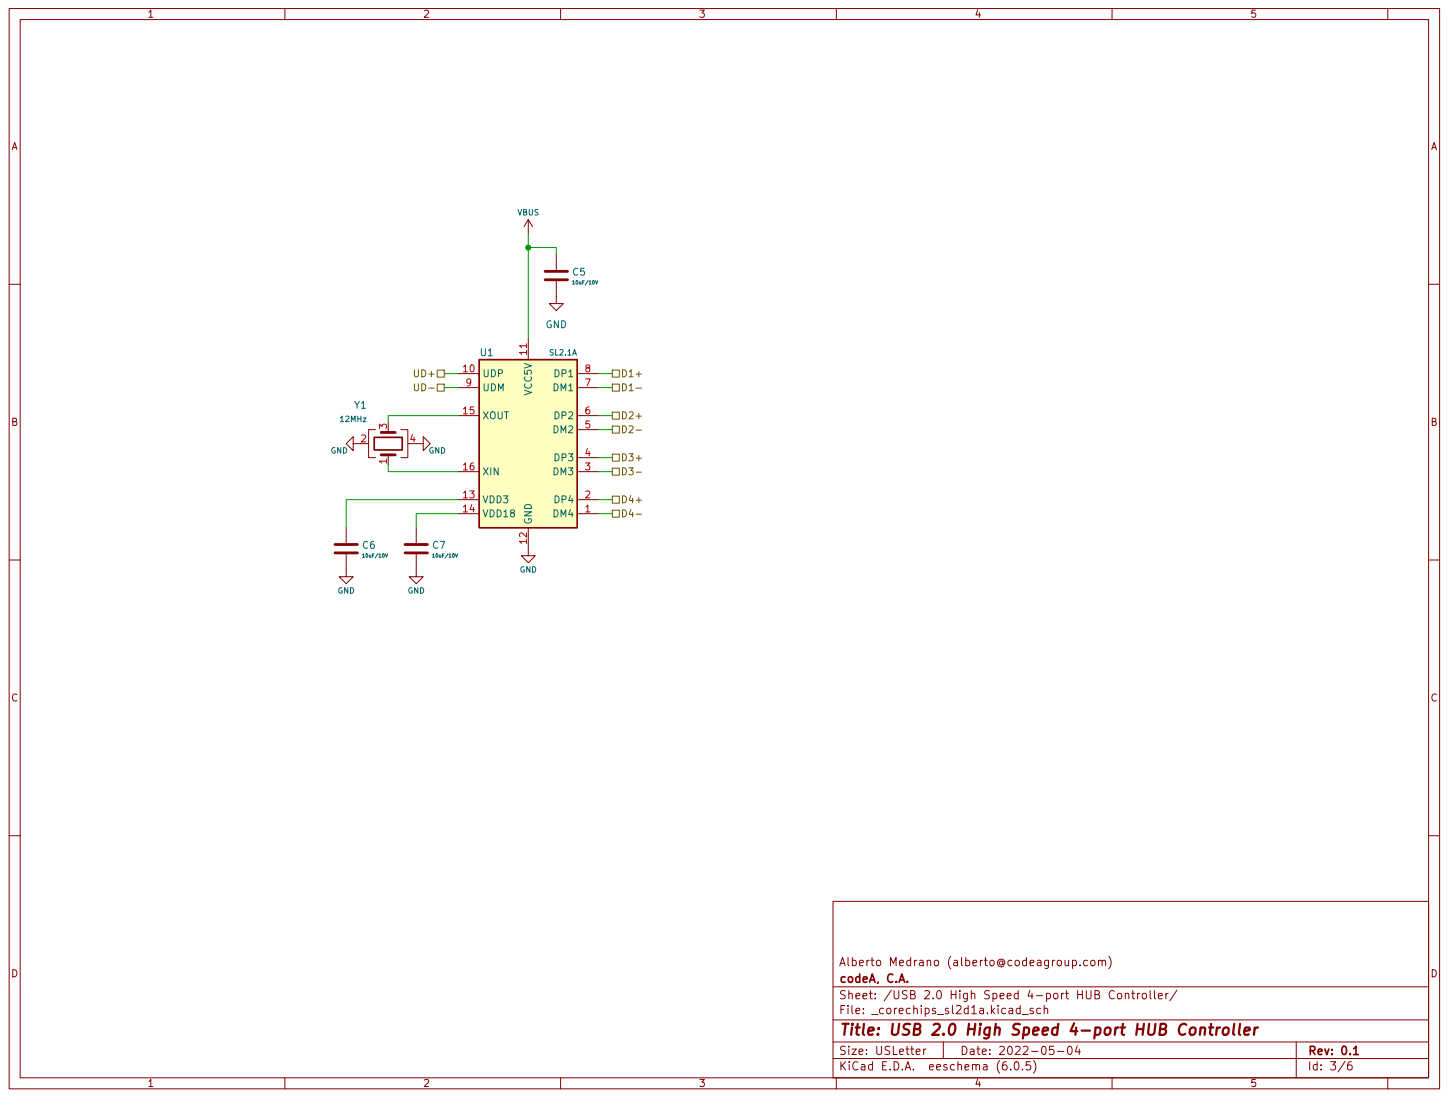
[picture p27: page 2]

Alberto Medrano (alberto@codeagroup.com)
codeA, C.A.
Sheet: /USB 2.0 High Speed 4-port HUB Controller/
File: _corechips_sl2d1a.kicad_sch
Id: 3/6 Title: USB 2.0 High Speed 4-port HUB Controller

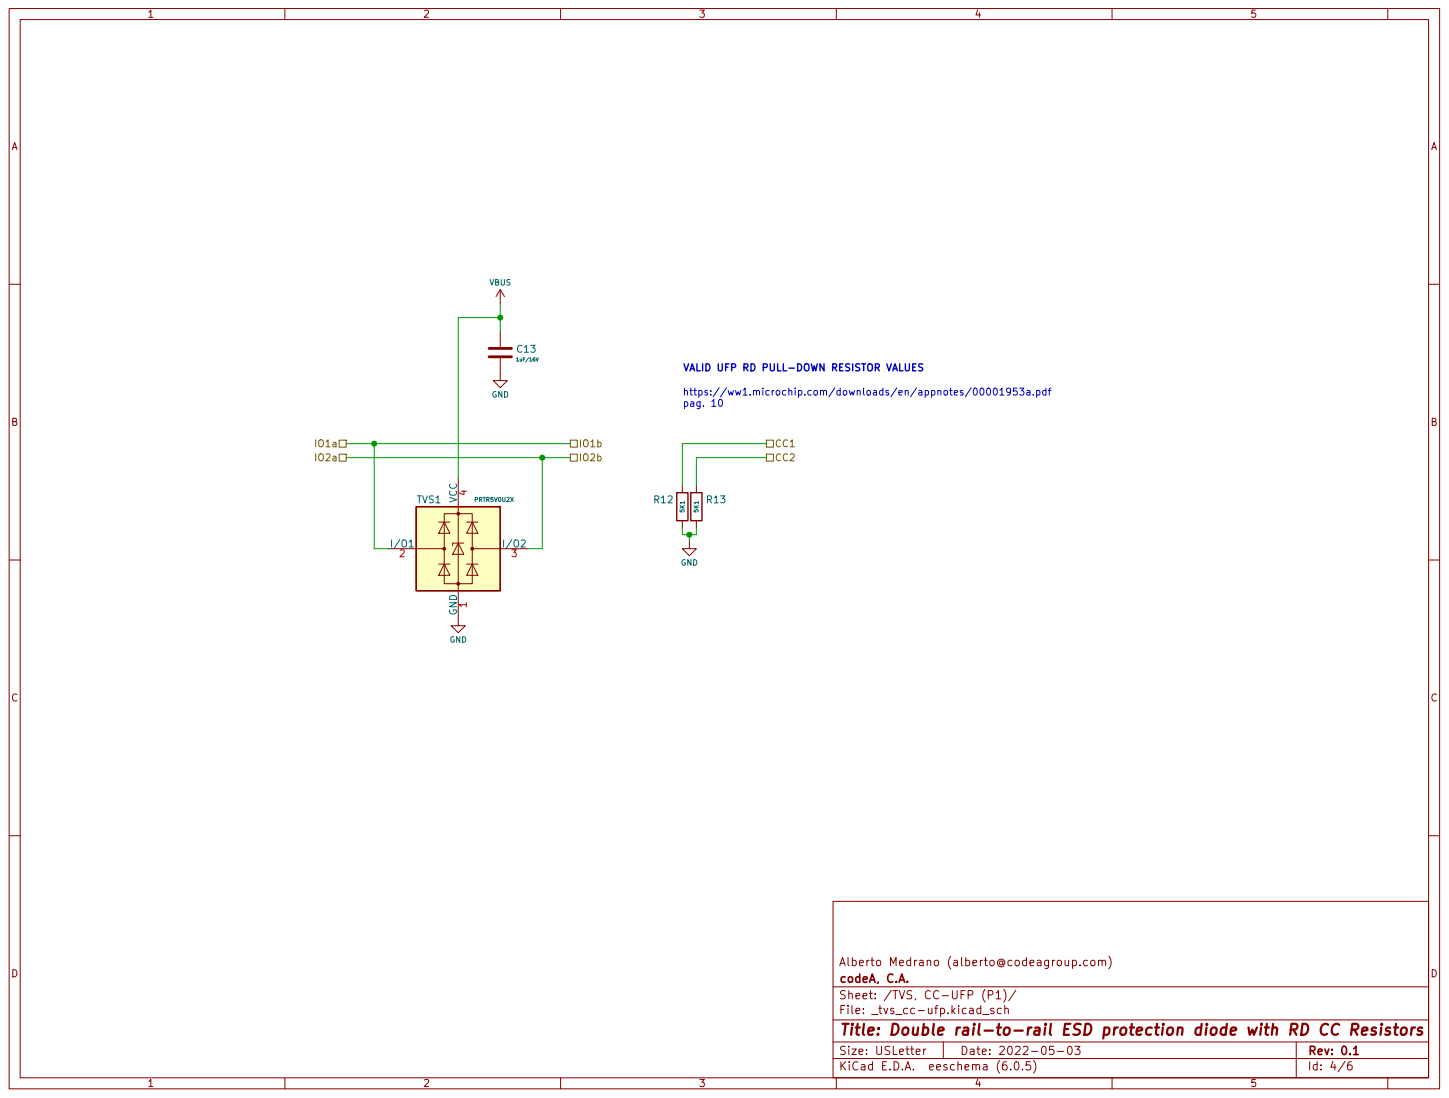
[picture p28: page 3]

https://ww1.microchip.com/downloads/en/appnotes/00001953a.pdf pag. 10 VALID UFP RD PULL-DOWN RESISTOR VALUES

codeA, C.A.
Sheet: /TVS, CC-UFP (P1)/
File: _tvs_cc-ufp.kicad_sch
Id: 4/6 Title: Double rail-to-rail ESD protection diode with RD CC Resistors

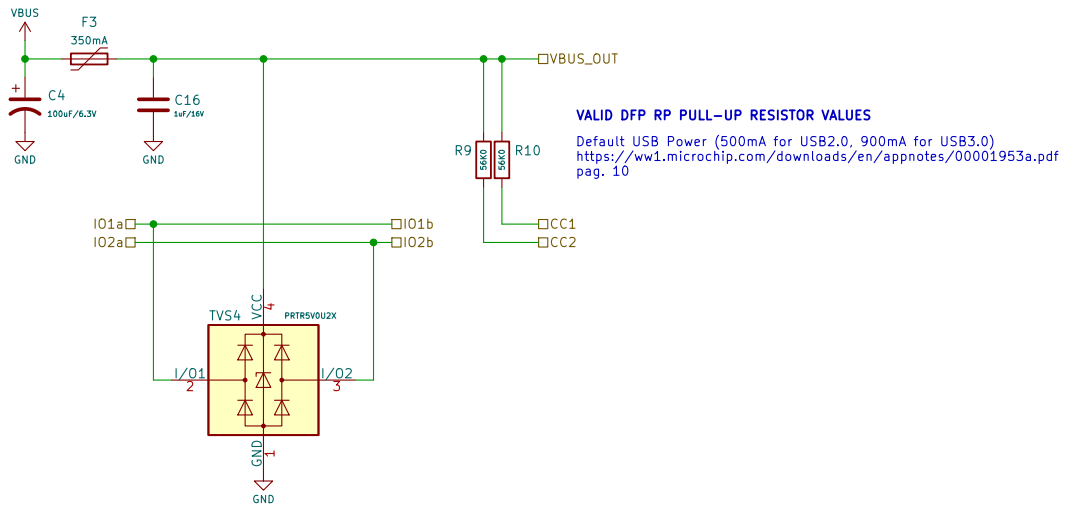
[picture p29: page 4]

https://ww1.microchip.com/downloads/en/appnotes/00001953a.pdf
pag. 10

Alberto Medrano (alberto@codeagroup.com)
codeA, C.A.
Sheet: /Protective, VBUS 2.0 (P4)/
File: _tvs_cc-dfp_pfuse.kicad_sch
Id: 6/6 Title: Double rail-to-rail ESD protection diode with RP CC Resistors

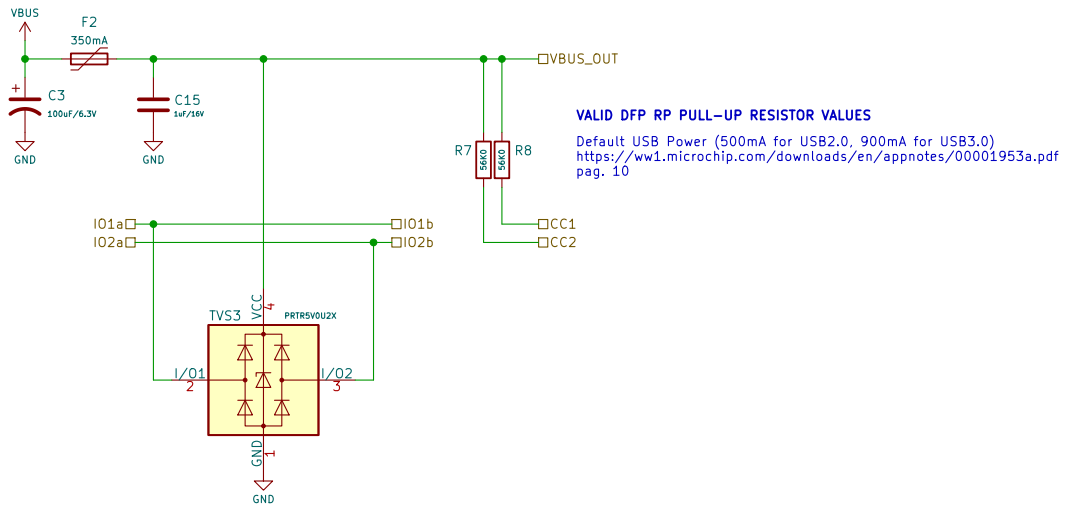
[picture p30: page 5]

https://ww1.microchip.com/downloads/en/appnotes/00001953a.pdf
pag. 10

Alberto Medrano (alberto@codeagroup.com)
codeA, C.A.
Sheet: /Protective, VBUS 2.0 (P3)/
File: _tvs_cc-dfp_pfuse.kicad_sch
Id: 7/6 Title: Double rail-to-rail ESD protection diode with RP CC Resistors

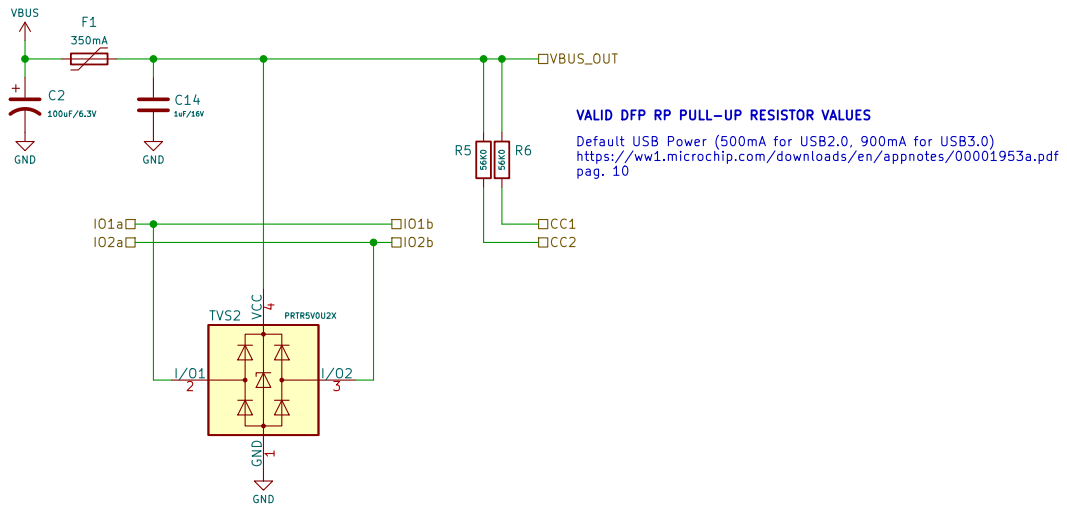
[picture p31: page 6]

https://ww1.microchip.com/downloads/en/appnotes/00001953a.pdf
pag. 10

Alberto Medrano (alberto@codeagroup.com)
codeA, C.A.
Sheet: /TVS, CC-DFP, PTC (P2)/
File: _tvs_cc-dfp_pfuse.kicad_sch
Id: 8/6 Title: Double rail-to-rail ESD protection diode with RP CC Resistors

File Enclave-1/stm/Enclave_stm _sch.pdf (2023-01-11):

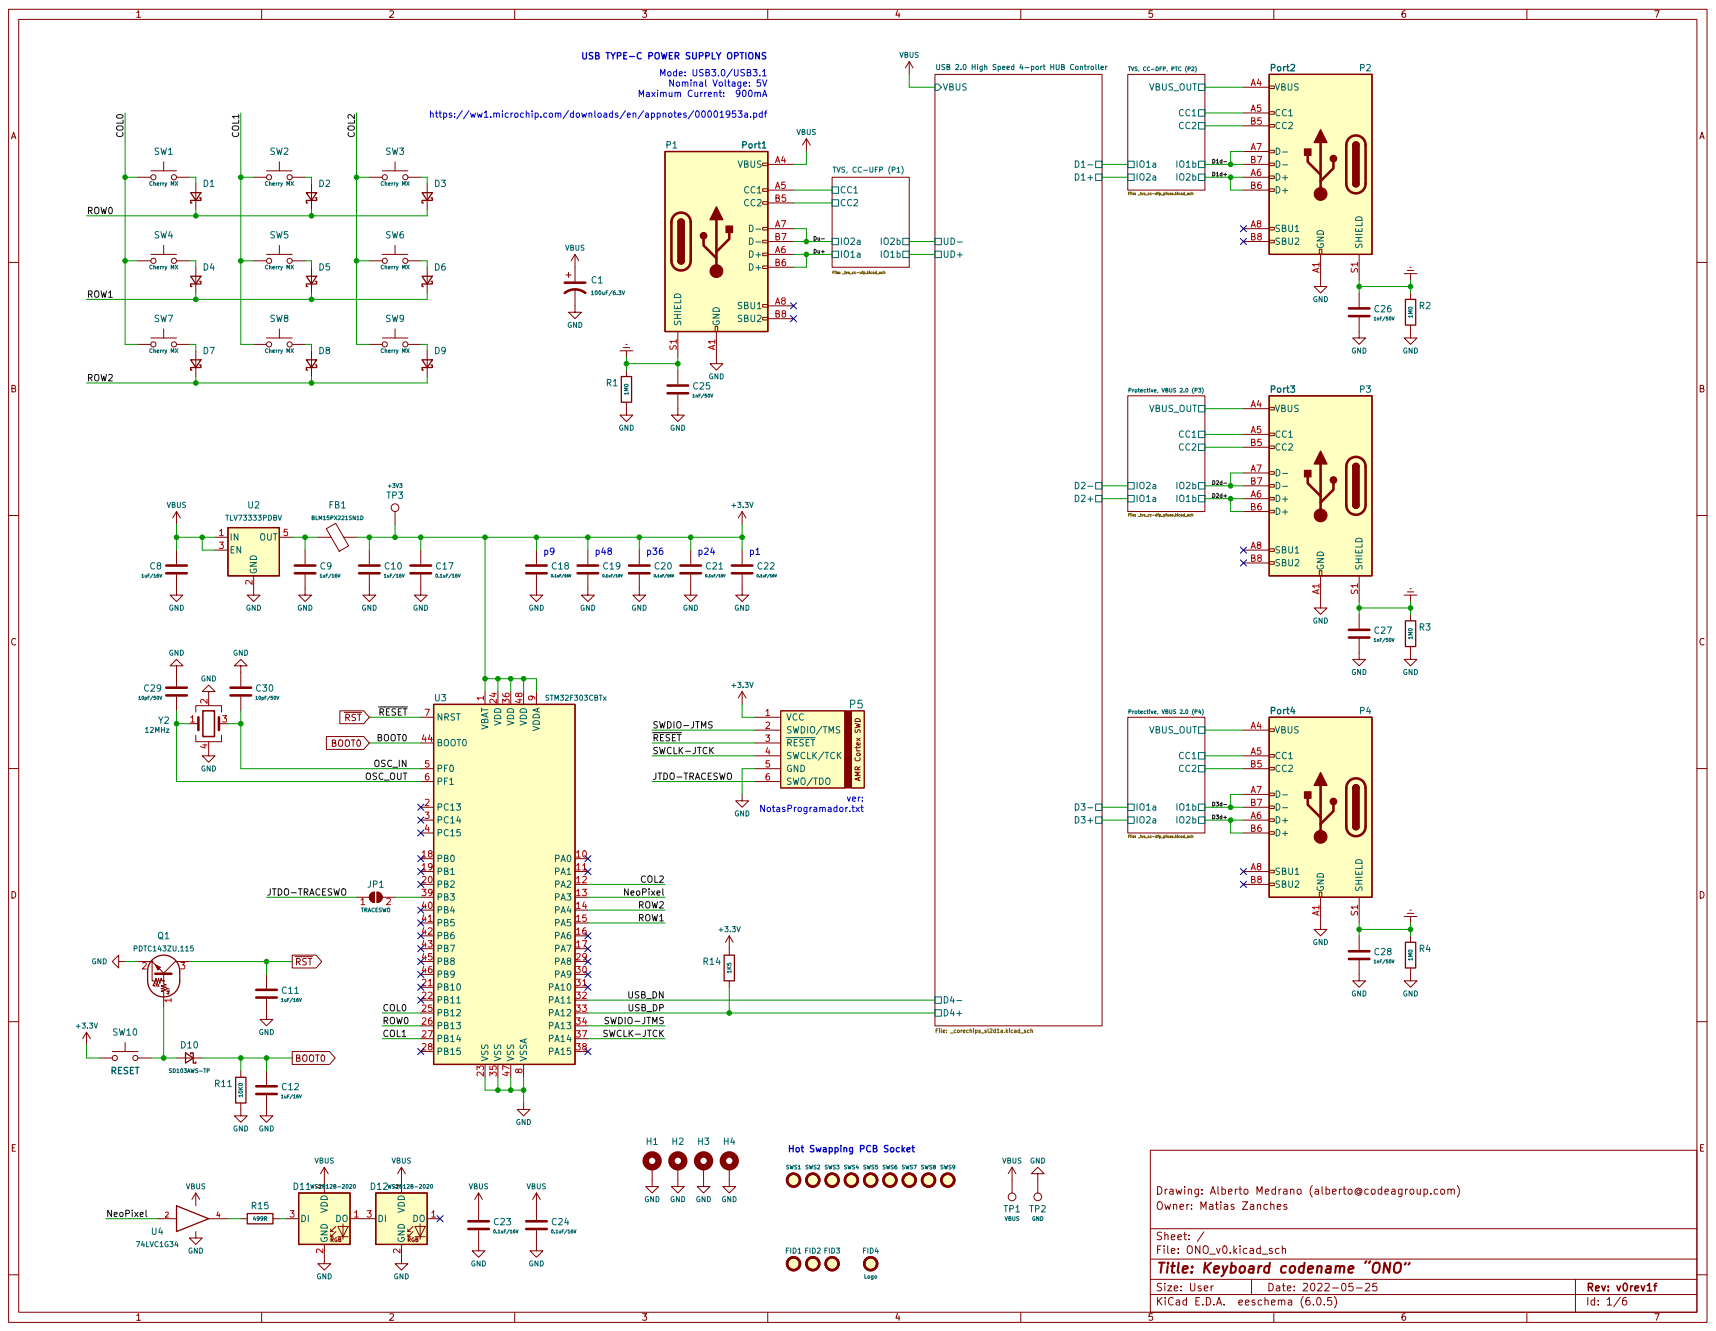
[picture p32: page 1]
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

TVS, CC-DFP, PTC (P2) File: _tvs_cc-dfp_pfuse.kicad_sch SW3

USB 2.0 High Speed 4-port HUB Controller

1 PA0 10 PA1 11 PA2 12 PA3 13 PA4 14 PA5 15 PA6 16 PA7 17 PB0 18 PB1 19 PC13 2 PB2 20 PB10 21 PB11 22 VSS 23 VDD 24 PB12 25 PB13 26 PB14 27 PB15 28 PA8 29 PC14 3 PA9 30 PA10 31 PA11 32 PA12 33 PA13 34 VSS 35 VDD 36 PA14 37 PA15 38 PB3 39 PC15 4 PB4 40 PB5 41 PB6 42 PB7 43 BOOT0 44 PB8 45 PB9 46 VSS 47 VDD 48 PF0 5 PF1 6 NRST 7 VSSA

Id: 1/6 þÿTitle: Keyboard codename ONO  File: ONO_v0.kicad_sch Sheet: / Owner: Matias Zanches Drawing: Alberto Medrano (alberto@codeagroup.com)

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


https://ww1.microchip.com/downloads/en/appnotes/00001953a.pdf
pag. 10

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


https://ww1.microchip.com/downloads/en/appnotes/00001953a.pdf
pag. 10

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


https://ww1.microchip.com/downloads/en/appnotes/00001953a.pdf
pag. 10

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

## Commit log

2023-01-11 files added
    [FR-4_plate_V1.dxf, Outline.dxf, Rev_logo.dxf]
2023-01-23 Updated folder str
    [Case_one_part.step, FR-4_plate_V1.dxf, Outline.dxf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]
2023-02-13 Added Topo
    [#v1_Outline.dwg, LED_OPSCO-Optoelectronics_SK6812MINI-E.step, PinHeader_1x04_Amphenol_10112684-G03-04ULF.step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]
